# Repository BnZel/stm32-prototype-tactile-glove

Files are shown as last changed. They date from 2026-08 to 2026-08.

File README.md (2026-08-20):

# STM32 Tactile Glove Experiment (Prototype)

An experiment first testing the **index finger** wearable prototype. This concept can be applied throughout all the fingers. 

Equipped with custom joint flex tracking with SMD potentiometers and tactile feedback with velostat and solder wick. 

### Background
An upgrade from my two previous sensor gloves, my blog posts share the continuous iteration:
* [Sensor Glove V1](https://bnzel.github.io/2024-11-13-Crude-Sensor-Glove/)
* [Sensor Glove V2](https://bnzel.github.io/2025-07-10-Sensor-Glove-V2/)

#### Features
* Custom Index Finger Cuffs.
* **Joint Flex Tracking:**
    * Dual potentiometers capturing real time rotational movement.
* **Multi Regional Force Sensing:**
    * Velostat and solder wick combination to create a **Force Sensitive Resistor** to the fingers: **[Distal Phalanges, Middle Phalanges, Proximal Phalanges](https://encrypted-tbn0.gstatic.com/images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)**.
* **Custom Dashboard:**
    * Python GUI that connects to serial output and reads incoming data to process and plots them in real time.

### Demo
https://github.com/user-attachments/assets/46218729-9e85-47b5-97d2-6f6d8990b069

https://github.com/user-attachments/assets/2a04278b-734e-488a-b526-99382673ec98

### Resources
> List of **tutorial references** are comments in **[./pyqt_gui/init.py](./pyqt_gui/__init__.py)** and **[./sensor_glove/r_hand.py](./sensor_glove/r_hand.py)**

#### Hardware
* STM32 BlackPill V3.1
* **[Bourns 33882 - 12 mm Rotary Position Sensor](https://www.digikey.ca/en/products/detail/bourns-inc/3382G-1-103G/1944266)**
* Three 3.3K Resistors
* Velostat & Solder wick
* Ribbon cables
* **[Custom 3D Printed Cuffs](./freecad/)**

#### Software
* **[FreeCAD](https://www.freecad.org/)**
* **Python:**
    * **[PyQT6](https://www.riverbankcomputing.com/software/pyqt/)** and **[PyQTGraph](https://www.pyqtgraph.org/)**
    * **[pglive](https://github.com/domarm-comat/pglive)** *pip package* for live plots
    * For both working with the GUI and microcontroller: **[requirements.txt](./pyqt_gui/requirements.txt)**

### In Depth Overview

#### How To Run
To run both the **STM32** and **GUI**, ensure you have the following:
* Python environment
* **requirements.txt**

To run the **Python GUI**:
Change to the *'[./pyqt_gui](./pyqt_gui/)'* directory and run *'[main.py](./pyqt_gui/main.py)'*.

To upload and run the **STM32**:
Change to the *'[./sensor_glove](./sensor_glove/)'* directory

Upload
```
mpremote connect /dev/YOUR_PORT fs cp r_hand.py :r_hand.py
mpremote connect /dev/YOUR_PORT fs cp main.py :main.py
mpremote run main.py
```

Once the port is connected, run: 
``` 
mpremote 
```

##### Linux or WSL
You may copy and paste these to shell scripts without switching to your python environment:

##### Uploading Firmware
```bash
eval "$(YOUR_ENV shell.YOUR_SHELL hook)"
YOUR_ENV activate YOUR_PYTHON_ENV
mpremote connect /dev/YOUR_PORT fs cp r_hand.py :r_hand.py
mpremote connect /dev/YOUR_PORT fs cp main.py :main.py
mpremote run main.py
```

##### Accessing REPL
```bash
eval "$(YOUR_ENV shell.YOUR_SHELL hook)"
conda activate YOUR_PYTHON_ENV
mpremote
```

#### Flowcharts

##### Python Graphical User Interface
```mermaid
flowchart TD
    A([Connect Serial]) --> B{Port Connected?} 
    B ==> |Yes| C{SerialThread Running?}
    B ==> |No| D{Retry?}
    D ==> |Yes| B
    D ==> |No| E([End])
    C ==> |Yes| F[Read Serial Output]
    C ==> |No| G[Create and Start SerialThread]
    G ==> C
    F ==> H[Process as CSV]
    H ==> I[Display to Textarea and Liveplots]
    I ==> J{Stop Serial?}
    J ==> |Yes| E
    J ==> |No| F
```
##### Firmware STM32 Blackpill

```mermaid
flowchart TD
    A([Initialize ADC pins and R_HAND configurations]) ==> B[Convert FSR and Potentiometer values]
    B ==> C[Compute DP, MP, PP to calculate_fsr]
    C ==> D{Voltage Output >= VCC - 0.001?}
    D ==> |Yes| E[Set FSR value to maximum resistance clamp]
    D ==> |No| F[Set FSR value to minimum resistance clamp]
    E ==> G[Calculate FSR]
    F ==> G
    G ==> H[Get Pressure Status]
    H ==> I{Does Pressure Calibration Values exist?}
    I ==> |Yes| J[Return and Assign Value]
    I ==> |No| K[Return N/A]
    J ==> L[Calculate Conductance]
    K ==> L
    L ==> M[Convert to Newtons]
    M ==> N[Convert to Grams]
    N ==> O[Process and Send to GUI]
    O ==> P[Print to Serial Output in CSV format]
    P ==> Q[Sleep 50ms]
    Q ==> R([Loop])
    R ==> C

```

#### Schematic
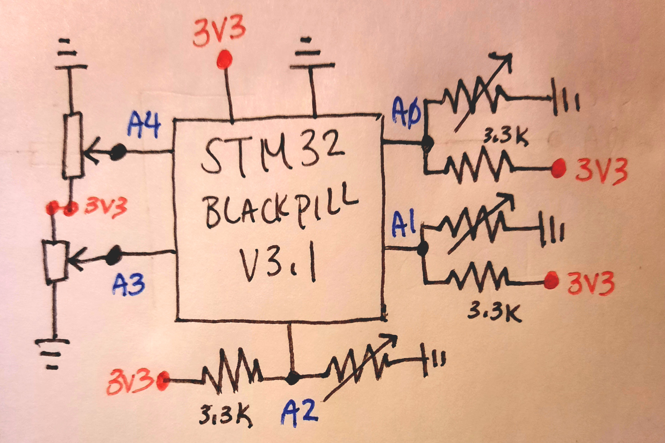
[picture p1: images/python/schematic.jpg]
schematic


#### Finger Cuffs
The cuffs are separated into **three parts** based on the anatomy of our fingers: 
* Distal Phalanges : DP **&rarr;** TOP
* Middle Phalanges : MP **&rarr;** MIDDLE
* Proximal Phalanges : PP **&rarr;** BOTTOM

It is already separated and placed into the **[freecad directory](./freecad/)** as **[STLs](./freecad/stls/)** and the original project file.

Each cuffs has their own potentiometer mounts where an extender arm goes through the shaft in order to create rotational movement.

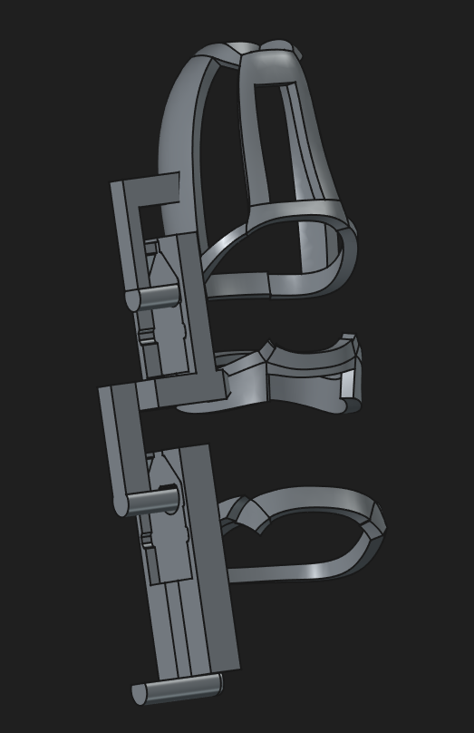
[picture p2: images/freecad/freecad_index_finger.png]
freecad_index_finger


#### Glove
The velostat is sandwiched between the solder wicks to create a flexible conductive electrode. There is a **[helpful tutorial that explains how to do this](https://www.youtube.com/watch?v=seMVgJ41BZw)**.

To cover as much surface area of each region, I decided to use a **3x3 matrix** layout on both **DP** and **PP**. **MP** is **1x1 matrix**. They are taped together on each region first with Kapton tape then secured to the cuffs with clear tape.

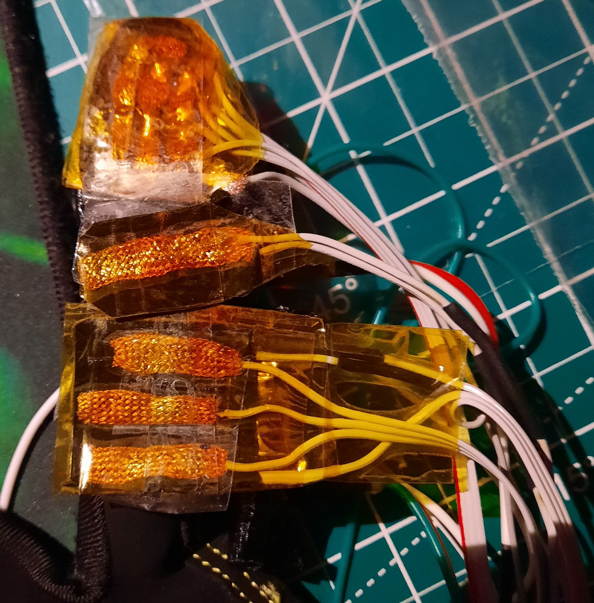
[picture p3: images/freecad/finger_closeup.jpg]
finger_closeup


glove_front_setup

The potentiometers VCC and GND are chained while their analog pins are separately wired to the BlackPill. 

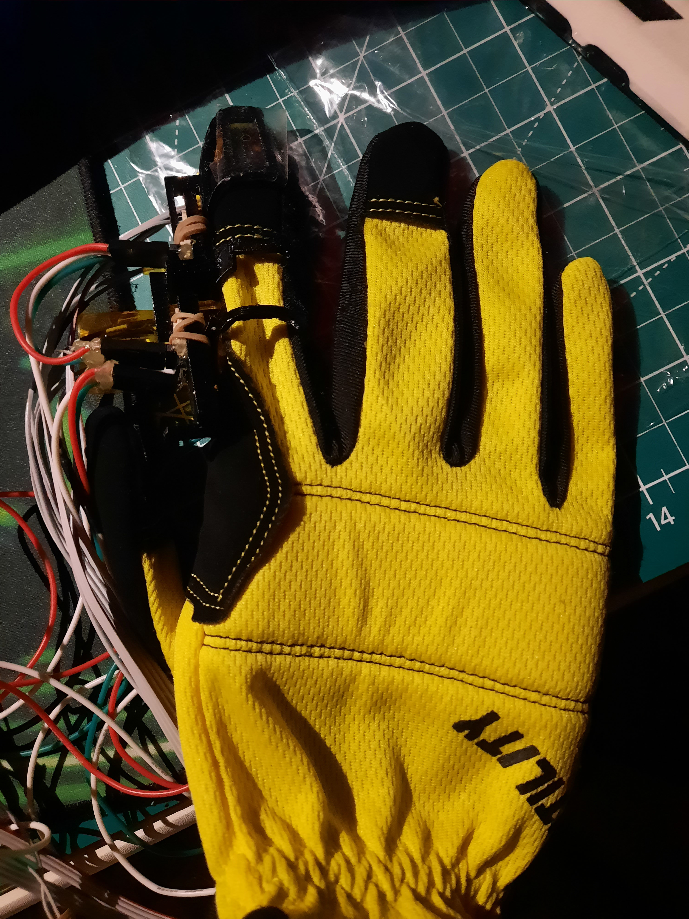
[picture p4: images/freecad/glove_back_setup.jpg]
glove_back_setup


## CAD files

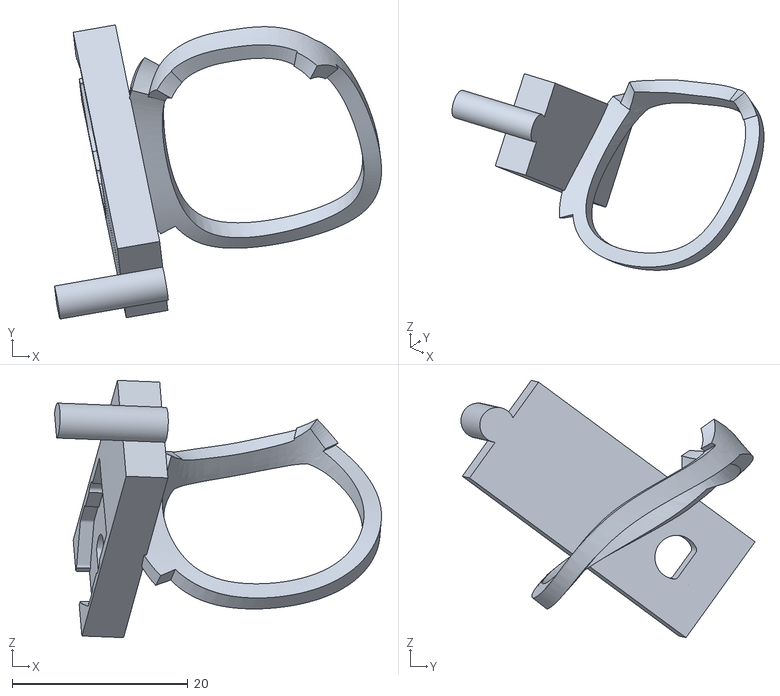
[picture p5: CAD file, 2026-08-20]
freecad/stls/POT3_PP_sensor_glove_V3.stl
37.2 x 33.4 x 29.3

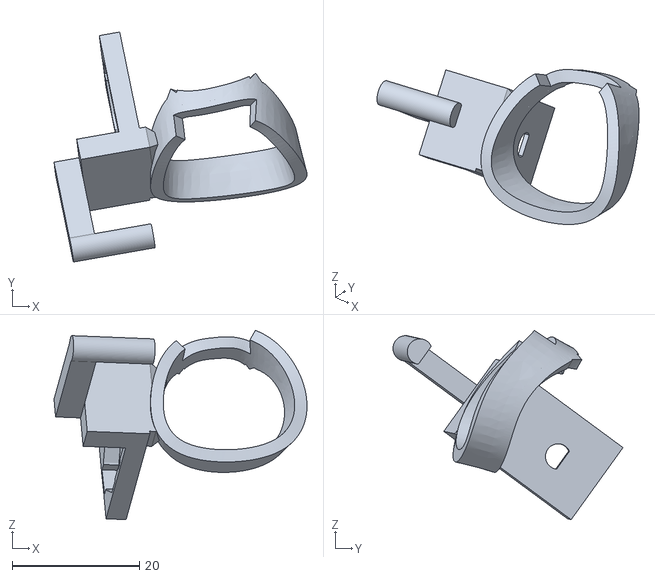
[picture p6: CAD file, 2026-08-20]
freecad/stls/POT2_MP_sensor_glove_V3.stl
39.7 x 36.1 x 29.7

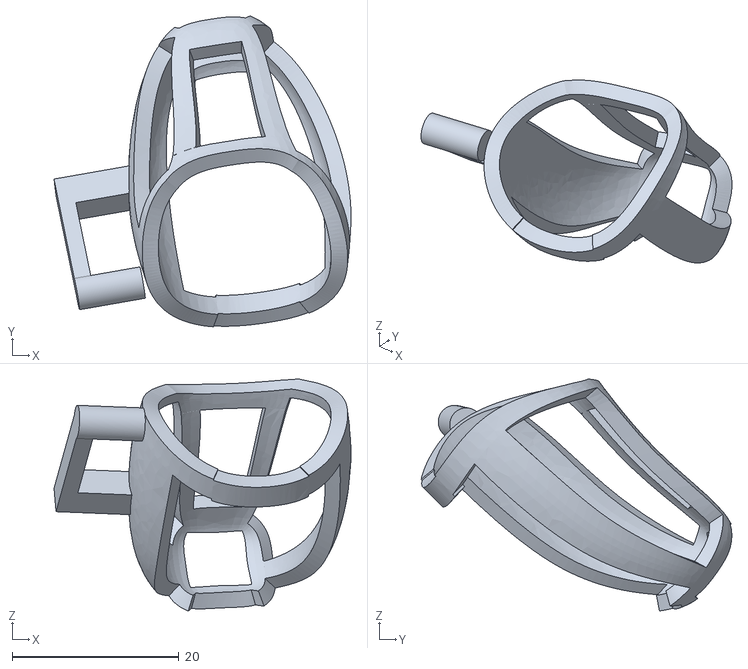
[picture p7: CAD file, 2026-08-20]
freecad/stls/POT1_DP_sensor_glove_V3.stl
35.6 x 37.3 x 27.8

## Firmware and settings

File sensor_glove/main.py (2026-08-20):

from machine import Pin, ADC
from time import sleep
from r_hand import *

# PRESSURE SENSORS
idx_dp_ps = ADC(R_HAND['INDEX']['PINS']['DP'][0])
idx_mp_ps = ADC(R_HAND['INDEX']['PINS']['DP'][1])
idx_pp_ps = ADC(R_HAND['INDEX']['PINS']['DP'][2])

# POTENTIOMETERS
idx_dp_pot1 = ADC(R_HAND['INDEX']['PINS']['DP'][3])
idx_mp_pot2 = ADC(R_HAND['INDEX']['PINS']['DP'][4])

def to_voltage(raw_adc,vcc=3.3,max_val=4095):
    adc = raw_adc.read_u16() >> 4
    return adc * (vcc / max_val)

def to_angle(raw_adc, max_adc=4095, max_angle=330):
    adc = raw_adc.read_u16() >> 4
    return int((adc / max_adc) * max_angle)

while True:
    voltage_dp = to_voltage(idx_dp_ps)
    voltage_mp = to_voltage(idx_mp_ps)
    voltage_pp = to_voltage(idx_pp_ps)

    pot1_angle = to_angle(idx_dp_pot1)
    pot2_angle = to_angle(idx_mp_pot2)

    status_dp, fsr_dp, conductance_dp, newtons_dp, grams_dp = calculate_fsr(voltage_dp, "DP")
    status_mp, fsr_mp, conductance_mp, newtons_mp, grams_mp = calculate_fsr(voltage_mp, "MP")
    status_pp, fsr_pp, conductance_pp, newtons_pp, grams_pp = calculate_fsr(voltage_pp, "PP")

    # print(f"ANGLE => POT1: {pot1_angle}° | POT2: {pot2_angle}° || GRAMS => DP: {grams_dp} {status_dp} | MP: {grams_mp} {status_mp} | PP: {grams_pp} {status_pp}")
    print(f"{pot1_angle},{pot2_angle},{grams_dp},{status_dp},{grams_mp},{status_mp},{grams_pp},{status_pp}")

    sleep(0.05) 

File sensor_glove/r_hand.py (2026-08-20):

# REFERENCES:
# https://blog.embeddedexpert.io/?p=3257
# https://andykong.org/blog/velostatlinqstat/
# https://www.fsrexpert.com/force-sensor-vs-pressure-sensor-the-real-difference-guide/
# https://learn.adafruit.com/force-sensitive-resistor-fsr/using-an-fsr


R_HAND = {
    'INDEX': 
            {
                'PINS': {'DP':['A0','A1','A2','A3','A4']}, 
                'PRESSURE':{'DP':[("NONE", 2.5), ("LIGHT", 2.3), ("MEDIUM", 1.6), ("HEAVY", 1.2)],
                            'MP':[("NONE", 2.0), ("LIGHT", 2.2), ("MEDIUM", 1.7), ("HEAVY", 1.2)],
                            'PP':[("NONE", 2.8), ("LIGHT", 1.6), ("MEDIUM", 1.3), ("HEAVY", 1.2)]
                            }
            }
}



def pressure_status(vout,region):
    '''
    Using baseline data to label force\n 
    "NONE", "LIGHT", "MEDIUM", "HEAVY"
    '''
    calib = R_HAND['INDEX']['PRESSURE']

    if region in calib:
        calib = calib.get(region)

        # NONE
        if vout >= calib[0][1]:
            return calib[0][0]

        # LIGHT
        elif vout >= calib[1][1]:
            return calib[1][0]

        # MEDIUM
        elif vout >= calib[2][1]:
            return calib[2][0]

        # HEAVY
        elif vout >= calib[3][1] or vout >= 0.7:
            return calib[3][0]
    else:
        return "N/A"
  

def calculate_fsr(vout, region, vcc=3.3, resistor=3300):
    '''
    FSR = (Vin - R) / (VCC - Vin)\n
    vout -> Velostat output voltage in millivolts (default is 3300 [3.3V])\n
    region -> Name of finger region ("DP","MP","PP")\n
    vcc -> Input voltage\n
    resistor -> Resistor value (default is 3300 [3.3K])\n\n

    Returns fsr, conductance, newtons, grams
    '''

    # handle division by zero
    # due to voltage spikes and noise
    # on 1 millivolt and setting
    # to high resistance to avoid crashing
    if vout >=  (vcc - 0.001):
        fsr = 999999.0
    elif vout <= 0.001:
        fsr = 0.001
    else:
        # this formula is the FSR 
        # low side (resistor connected to VCC)
        fsr = (vout * resistor) / (vcc - vout) 

    STATUS = pressure_status(vout, region)

    # convert to micromhos
    # to measure in newtons
    conductance = 1000000 / fsr  

    newtons = conductance / 80 if conductance <= 1000 else (conductance - 100) / 30

    # newtons to grams
    grams = newtons * 101.9716

    return STATUS, round(fsr,2), int(conductance), round(newtons,2), round(grams,1)

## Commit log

2026-08-20 uploading images and README.md, renamed freecad stls
    [POT1_DP_sensor_glove_V3.stl, POT2_MP_sensor_glove_V3.stl, POT3_PP_sensor_glove_V3.stl]
2026-08-20 add schematic in ./images and mermaid python gui flowchart
2026-08-20 remove unused code in main.py in ./sensor_glove and added firmware flowchart for stm32
2026-08-20 updated firmware flowcharts descriptions and added loop to compute dp,mp,pp process
2026-08-20 Enhance README with clearer setup instructions
    Updated instructions for running the Python GUI and STM32 firmware upload. Clarified steps for using shell scripts and connecting to the device.
